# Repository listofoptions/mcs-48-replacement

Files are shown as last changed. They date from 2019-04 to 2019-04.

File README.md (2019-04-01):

# mcs-48-replacement
comaptible pinout controller for the mcs-48 microcontroller line using an AT90USB1286

features:
  - usb esd protection
  - power supply seperation and selection
  - reverse voltage protection (vcc/gnd swap)

  **__DO NOT ATTEMPT TO USE THIS CONTROLLER IN A MCS-48 PROGRAMMER__**
  **__THERE IS NO OVERVOLTAGE PROTECTION ON VDD, PROG, OR EA__**

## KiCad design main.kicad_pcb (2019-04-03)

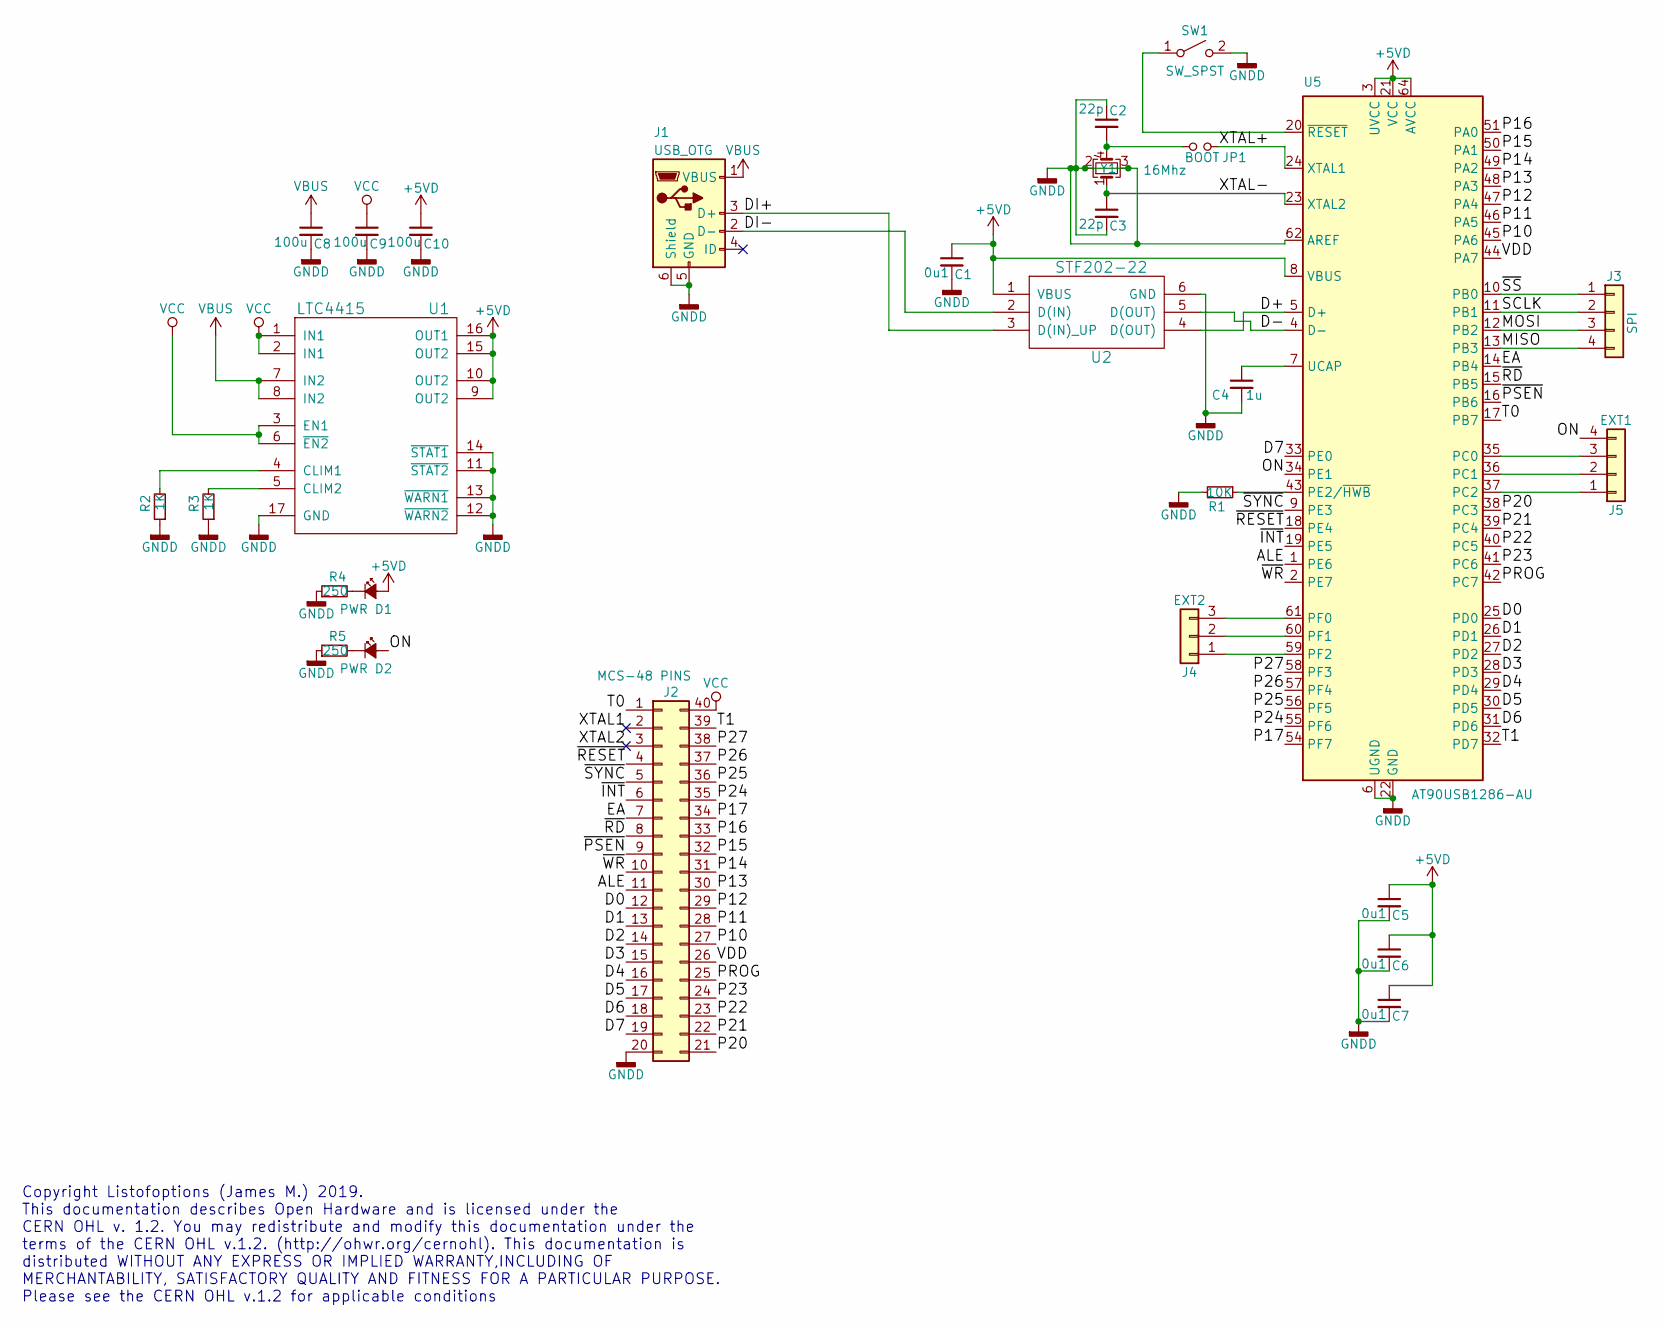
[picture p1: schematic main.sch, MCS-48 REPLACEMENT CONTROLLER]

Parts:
C1, C5, C6, C7: 0u1; C_0201
C2, C3: 22p; C_0201
C4: 1u; C_0201
C8, C9, C10: 100u; C_0805
D1, D2: PWR; LED_0402
J1: USB_OTG; USB_Micro-B_Molex-105017-0001
J2: MCS-48 PINS; DIP-40_W15.24mm
J3: SPI; Pin_Header_Straight_1x04_Pitch1.00mm
J4: EXT2; Pin_Header_Straight_1x03_Pitch1.00mm
J5: EXT1; Pin_Header_Straight_1x04_Pitch1.00mm
JP1: BOOT; R_0201_NoSilk
R1: 10K; R_0402
R2, R3: 1K; R_0402
R4, R5: 250; R_0402
SW1: SW_SPST; SW_SPST_B3U-3000P
U1: LTC4415; DFN-16-1EP_3x5mm_Pitch0.5mm
U2: STF202-22; TSOP-6_1.65x3.05mm_Pitch0.95mm
U5: AT90USB1286-AU; QFN-64-1EP_9x9mm_Pitch0.5mm
Y1: 16Mhz; Crystal_SMD_2016-4pin_2.0x1.6mm

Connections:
+5VD: C1.1, C5.1, C6.1, C7.1, C10.1, D1.2 (A), U1.9 (OUT2), U1.10 (OUT2), U1.15 (OUT2), U1.16 (OUT1), U2.1 (VBUS), U5.3 (UVCC), U5.8 (VBUS), U5.21 (VCC), U5.52 (VCC), U5.64 (AVCC)
/ALE: J2.11, U5.1 (PE6)
/D0: J2.12, U5.25 (PD0)
/D1: J2.13, U5.26 (PD1)
/D2: J2.14, U5.27 (PD2)
/D3: J2.15, U5.28 (PD3)
/D4: J2.16, U5.29 (PD4)
/D5: J2.17, U5.30 (PD5)
/D6: J2.18, U5.31 (PD6)
/D7: J2.19, U5.33 (PE0)
/D+: U2.4 (D(OUT)), U5.5 (D+)
/D-: U2.5 (D(OUT)), U5.4 (D-)
/DI+: J1.3 (D+), U2.3 (D(IN)_UP)
/DI-: J1.2 (D-), U2.2 (D(IN))
/EA: J2.7, U5.14 (PB4)
/MISO: J3.4, U5.13 (PB3)
/MOSI: J3.3, U5.12 (PB2)
/ON: D2.2 (A), J5.4, U5.34 (PE1)
/P10: J2.27, U5.45 (PA6)
/P11: J2.28, U5.46 (PA5)
/P12: J2.29, U5.47 (PA4)
/P13: J2.30, U5.48 (PA3)
/P14: J2.31, U5.49 (PA2)
/P15: J2.32, U5.50 (PA1)
/P16: J2.33, U5.51 (PA0)
/P17: J2.34, U5.54 (PF7)
/P20: J2.21, U5.38 (PC3)
/P21: J2.22, U5.39 (PC4)
/P22: J2.23, U5.40 (PC5)
/P23: J2.24, U5.41 (PC6)
/P24: J2.35, U5.55 (PF6)
/P25: J2.36, U5.56 (PF5)
/P26: J2.37, U5.57 (PF4)
/P27: J2.38, U5.58 (PF3)
/PROG: J2.25, U5.42 (PC7)
/SCLK: J3.2, U5.11 (PB1)
/T0: J2.1, U5.17 (PB7)
/T1: J2.39, U5.32 (PD7)
/VDD: J2.26, U5.44 (PA7)
/XTAL+: JP1.2, U5.24 (XTAL1)
/XTAL-: C3.1, U5.23 (XTAL2), Y1.1
/~INT: J2.6, U5.19 (PE5)
/~PSEN: J2.9, U5.16 (PB6)
/~RD: J2.8, U5.15 (PB5)
/~RESET: J2.4, U5.18 (PE4)
/~SS: J3.1, U5.10 (PB0)
/~SYNC: J2.5, U5.9 (PE3)
/~WR: J2.10, U5.2 (PE7)
GNDD: C1.2, C2.1, C3.2, C4.2, C5.2, C6.2, C7.2, C8.2, C9.2, C10.2, J1.5 (GND), J1.6 (Shield), J2.20, R1.2, R2.1, R3.1, R4.1, R5.1, SW1.2 (B), U1.11 (~STAT2), U1.12 (~WARN2), U1.13 (~WARN1), U1.14 (~STAT1), U1.17 (GND), U2.6 (GND), U5.6 (UGND), U5.22 (GND), U5.53 (GND), U5.62 (AREF), U5.63 (GND), U5.65, Y1.2, Y1.3
unnamed: C2.2, JP1.1, Y1.4
unnamed: C4.1, U5.7 (UCAP)
unnamed: D1.1 (K), R4.2
unnamed: D2.1 (K), R5.2
unnamed: J4.1, U5.59 (PF2)
unnamed: J4.2, U5.60 (PF1)
unnamed: J4.3, U5.61 (PF0)
unnamed: J5.1, U5.37 (PC2)
unnamed: J5.2, U5.36 (PC1)
unnamed: J5.3, U5.35 (PC0)
unnamed: R1.1, U5.43 (PE2/~HWB)
unnamed: R2.2, U1.4 (CLIM1)
unnamed: R3.2, U1.5 (CLIM2)
unnamed: SW1.1 (A), U5.20 (~RESET)
VBUS: C8.1, J1.1 (VBUS), U1.7 (IN2), U1.8 (IN2)
VCC: C9.1, J2.40, U1.1 (IN1), U1.2 (IN1), U1.3 (EN1), U1.6 (~EN2)

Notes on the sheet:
Copyright Listofoptions (James M.) 2019. This documentation describes Open Hardware and is licensed under the CERN OHL v. 1.2. You may redistribute and modify this documentation under the terms of the CERN OHL v.1.2. (http://ohwr.org/cernohl). This documentation is distributed WITHOUT ANY EXPRESS O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

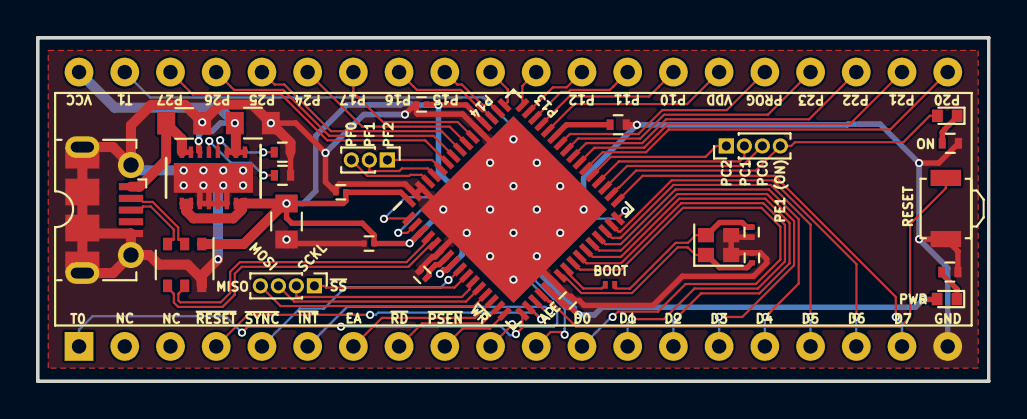
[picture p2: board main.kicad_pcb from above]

Board: 2 copper layers, 52.8 x 19.1 mm, 28 parts (0 on the bottom side), 65 nets.

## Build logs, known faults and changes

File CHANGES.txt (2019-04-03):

31/03/2019
        - initial commit and creation
        
04/01/2019
        - cleaned up differential traces
        - added legal shenanigans
        - added status leds
        
04/03/2019
	- improved ground plane
	- added beefier supply caps
	- text on pins
	- improved routing on differential signals and some others
	- added NO jumper on xtal-1 pin for programming bootloader

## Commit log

2019-04-01 intial commit, organization later
    [main.kicad_pcb, main.sch]
2019-04-01 cleaned up pcb, added status LEDs
    [main.kicad_pcb, main.sch]
2019-04-01 legal shenanigans
    [main.kicad_pcb, main.sch]
2019-04-03 improved groundplane, and used beefier supply caps
    [main.kicad_pcb, main.sch]
2019-04-03 shenanigans and bootloader jumper on clock xtal-1 pin
    [main.kicad_pcb, main.sch]
2019-04-03 last minute 3d-shenanigans
    [main.kicad_pcb]
